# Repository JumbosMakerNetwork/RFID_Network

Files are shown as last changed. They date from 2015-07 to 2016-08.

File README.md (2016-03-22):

# Jumbo's Maker Network - RFID Usage Tracking
This project is an RFID tag and arduino based system for tracking use in a makerspace while also integrating automated safety interlocks through use of data and power relays. 

This includes the firmware and hardware files for the system as well as a series of analytical software used to derive insightful data from the makerspace.

This project is currently in development, so if you stumble across this, please let us know if something doesn't work and feel free to comment to help out if you have some useful feedback.

## Hardware
Contains:
	-Eagle Files, used as design for fabricating circuit boards. There are a variety of circuit boards used in this project, the principal ones being a data interlock board used to interrupt serial communication between devices, and a Pro Shield board, which is used to connect all the components of the RFID reader (e.g. the Mifare Scanner, the LCD monitor..) to the Arduino ESP8266
	-Enclosure files, which are CAD schematics for 3d printing/laser cutting the enclosure that holds all the components

## Scripts
Contains:
	-Several scripts used to initialize new stations and users. These funcitons will eventually be encapsulated by a unified Python data model which will be used for all SQL functions.

## Source Code
Contains:
	-Arduino: the necessary libraries and source code needed for the Arduino microcontrollers powering this system. Within this repo are folders for Signin and Relay stations; Signin stations only have the funcitnality of signin/signout, whereas the relay terminals are capable of restricting power or serial communication between devices.
	-All the php and PSQL initialization tools used to create our PSQL database (in scripts and www)

## Web Analytics
Contains:
	-a set of documents that generate an HTML page featuring visualized data of makerspace usage and new membership over time. This data is collected with python scripts using the pyscopg module, and then interpreted with javascript files utilizing ajax and jquery, finally being visualized with the charts.js library.

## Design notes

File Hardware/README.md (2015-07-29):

# CEEO Makerspace Data Collection - Hardware

## Description
This will be for all the drawings for RFID fobs, terminal enclosures, and PCBs that support the system. 

## To Dos
- ~~ Design Enclosures ~~
- ~~ Finish PCBs ~~
- ~~ Design some RFID key fobs ~~
- ~~ Add Bill of Materials ~~

## Notes

Notes go here

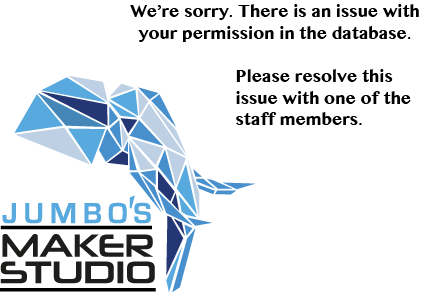
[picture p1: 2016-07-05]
Source_Code/labview/Images/No_ID.png

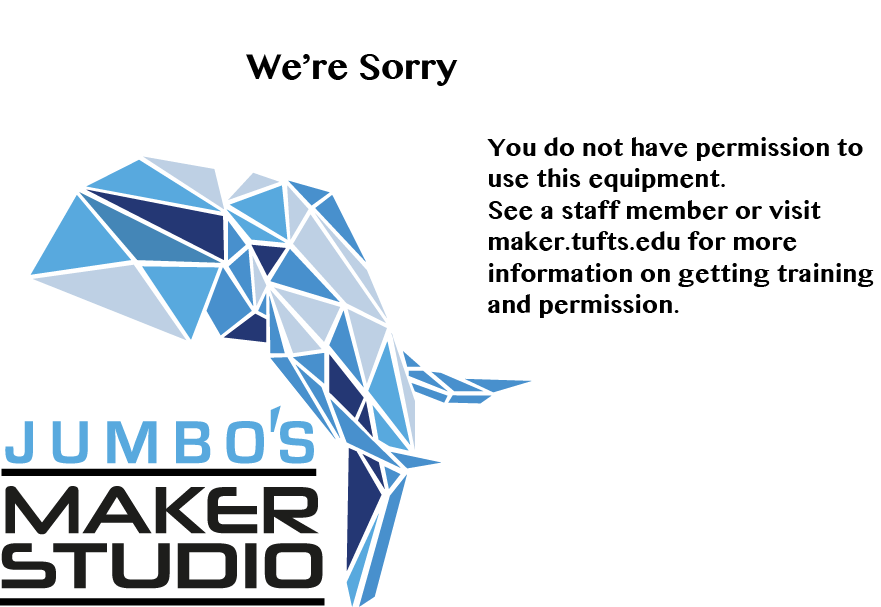
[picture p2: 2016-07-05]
Source_Code/labview/Images/Denied.png

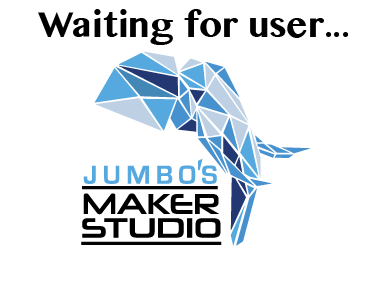
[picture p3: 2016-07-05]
Source_Code/labview/Images/Waiting.png

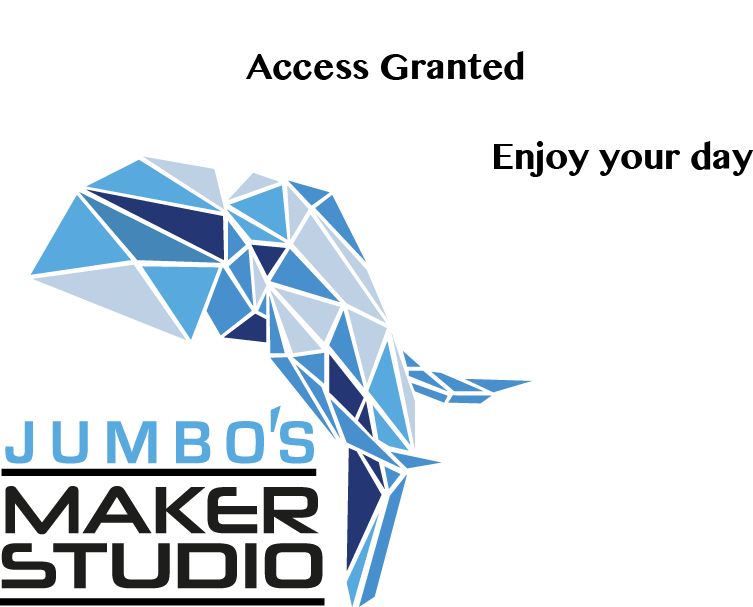
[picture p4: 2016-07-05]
Source_Code/labview/Images/Approve.png

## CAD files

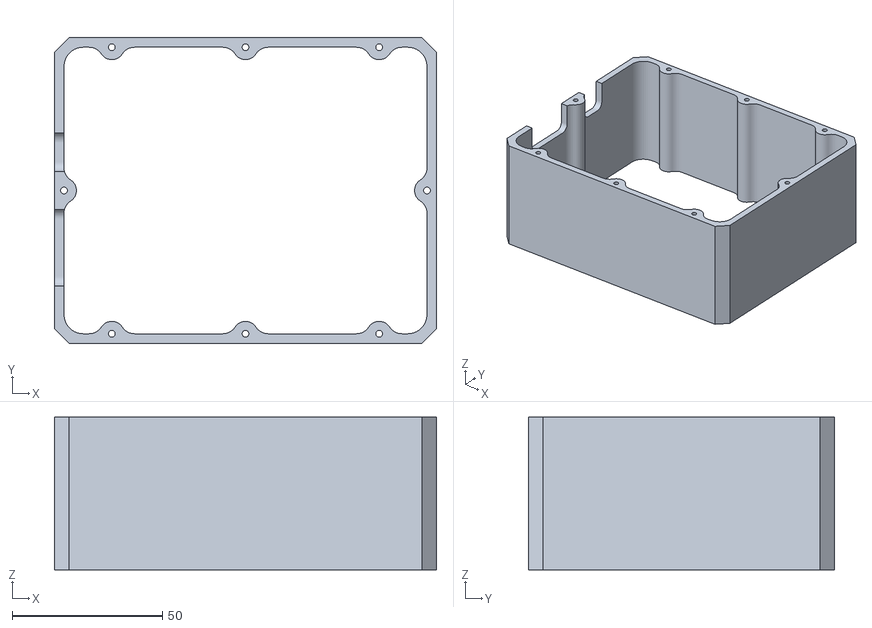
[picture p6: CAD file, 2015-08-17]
Hardware/Enclosure/Signin/Frame.STL
127.0 x 101.6 x 50.8

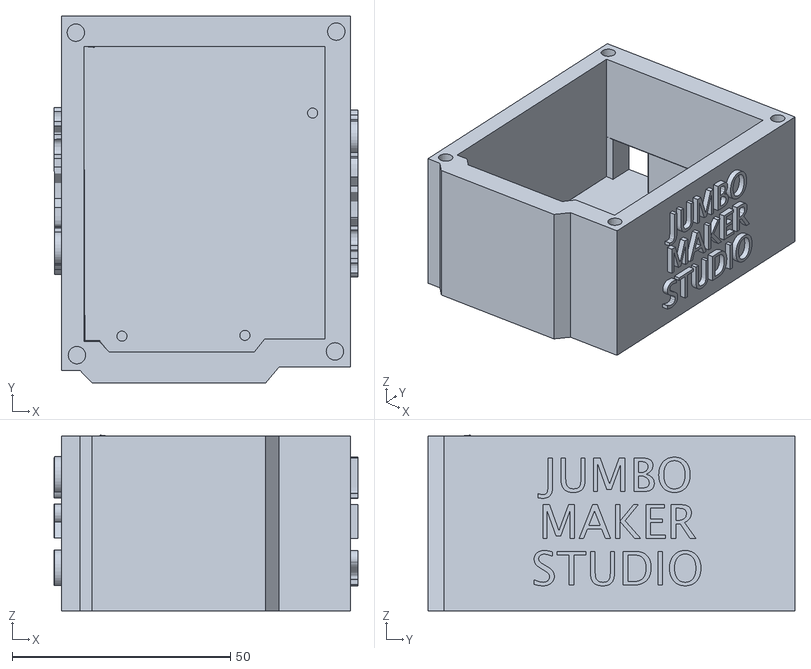
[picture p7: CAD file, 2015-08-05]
Hardware/Enclosure/Signin/V1/Signin Enclosure Bottom.stl
69.5 x 84.0 x 40.3

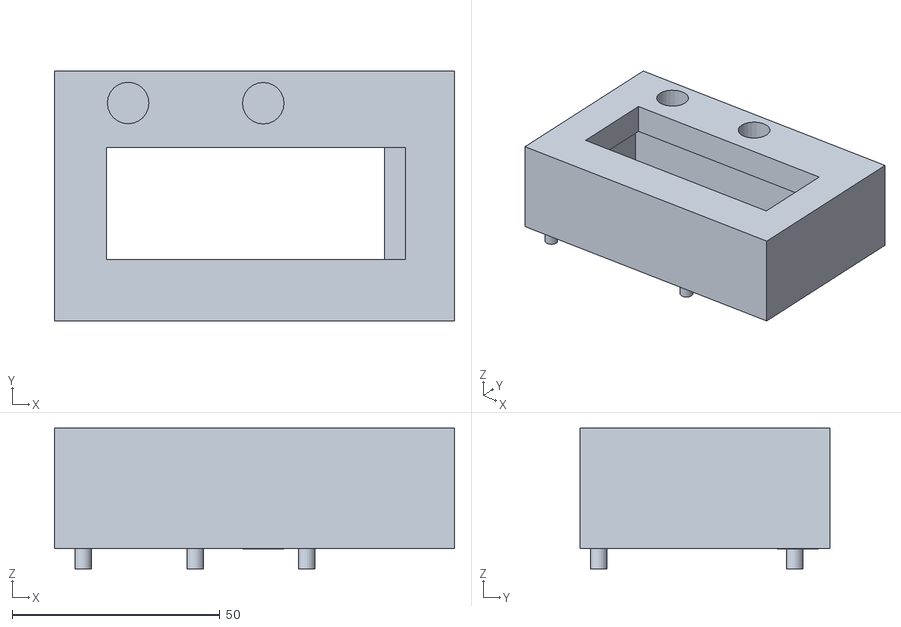
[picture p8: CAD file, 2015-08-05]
Hardware/Enclosure/Signin/V1/Signin Enclosure Top.stl
96.3 x 60.3 x 33.8

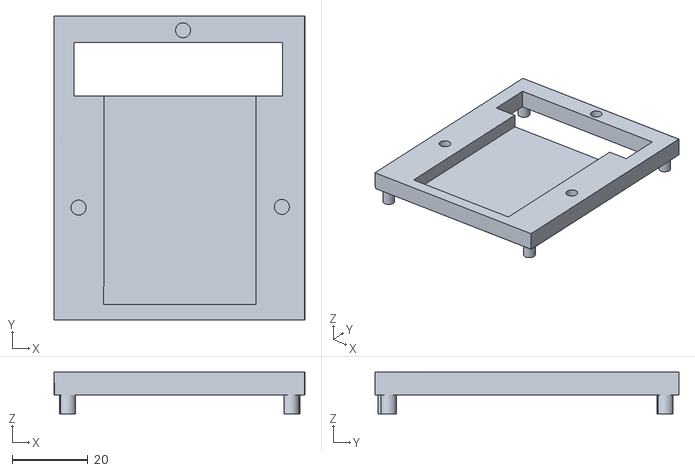
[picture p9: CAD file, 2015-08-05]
Hardware/Enclosure/Signin/V1/Signin Enclosure Middle.stl
66.4 x 80.4 x 11.0

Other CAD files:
Hardware/Enclosure/Signin/V1/SIgnInV1_Assy.skp
Hardware/Enclosure/Signin/V1/Signin Enclosure Bottom.skp
Hardware/Enclosure/Signin/V1/Signin Enclosure Bottom~.skp
Hardware/Enclosure/Signin/V1/Signin Enclosure Middle.skp
Hardware/Enclosure/Signin/V1/Signin Enclosure Top.skp

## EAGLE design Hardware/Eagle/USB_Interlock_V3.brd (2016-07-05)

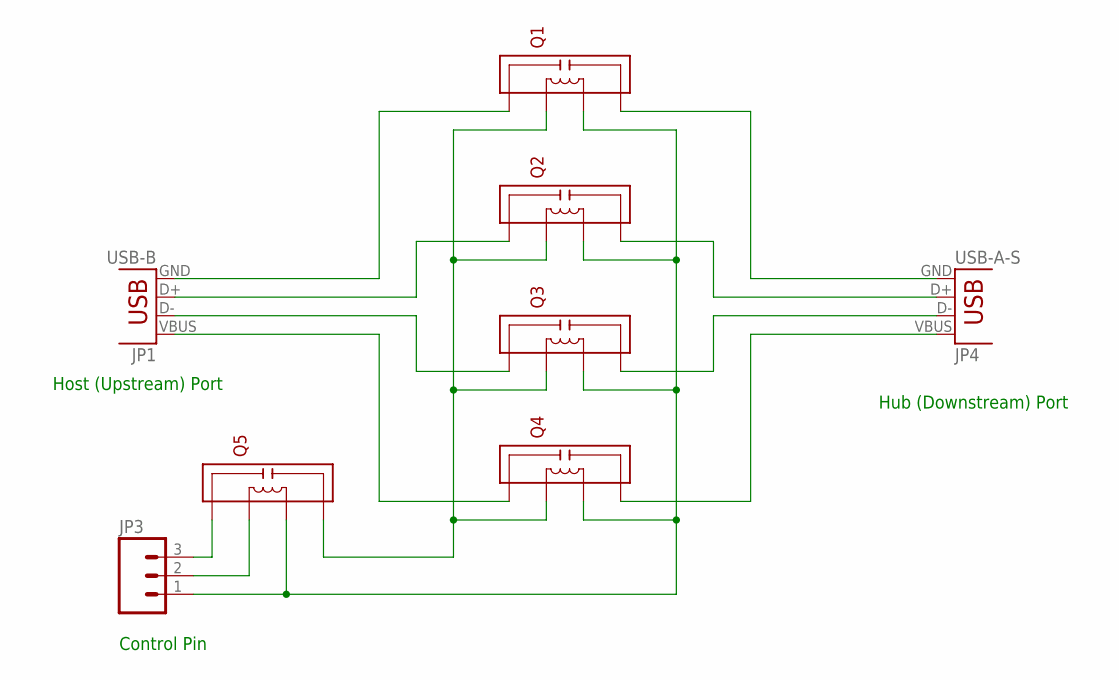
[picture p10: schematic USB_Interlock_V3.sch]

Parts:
JP1: USB-B; USB-B-PTH
JP3: M03LONGPADS; 1X03_LONGPADS
JP4: USB-A-S
Q1, Q2, Q3, Q4, Q5: 9007-12-01

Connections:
GND: JP3.1, Q1.P$3, Q2.P$3, Q3.P$3, Q4.P$3, Q5.P$3
HV1: JP4.D-, Q3.P$4
HV2: JP4.D+, Q2.P$4
LV1: JP1.D-, Q3.P$1
LV2: JP1.D+, Q2.P$1
unnamed: JP3.3, Q5.P$1
unnamed: JP3.2, Q5.P$2
unnamed: Q1.P$2, Q2.P$2, Q3.P$2, Q4.P$2, Q5.P$4
unnamed: JP1.GND, Q1.P$1
unnamed: JP4.GND, Q1.P$4
unnamed: JP1.VBUS, Q4.P$1
V1: JP4.VBUS, Q4.P$4

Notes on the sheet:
Hub (Downstream) Port
Host (Upstream) Port
Control Pin

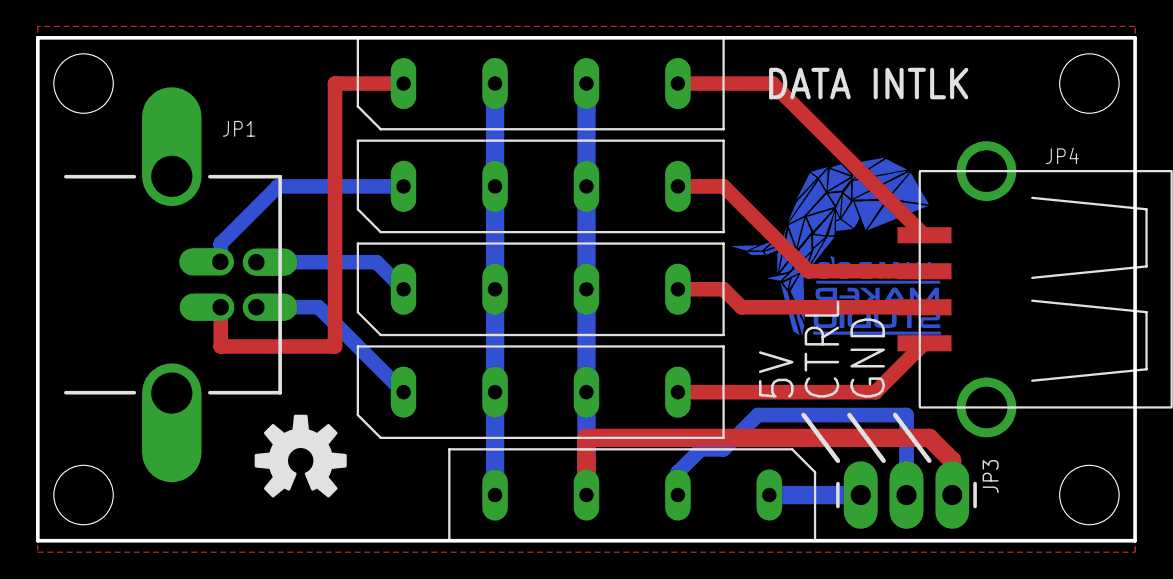
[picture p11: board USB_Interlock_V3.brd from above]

Board: 2 copper layers, 61.0 x 27.9 mm, 14 parts (1 on the bottom side), 12 nets.

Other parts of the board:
U$1: OSHW-LOGO-M
U$2, U$3, U$4, U$5: STAND-OFF
U$7: JMS_LOG_COPPER

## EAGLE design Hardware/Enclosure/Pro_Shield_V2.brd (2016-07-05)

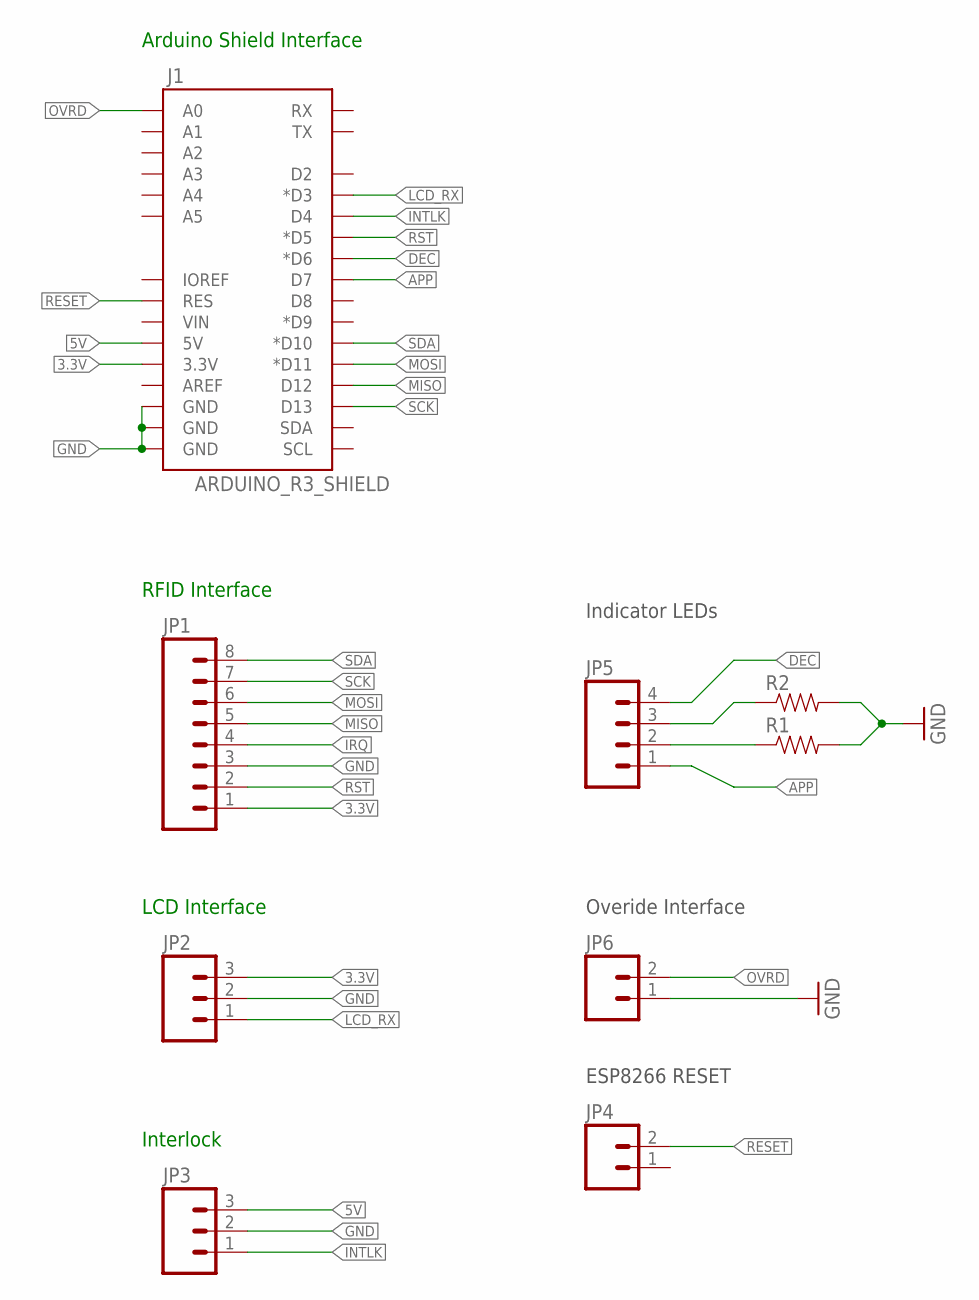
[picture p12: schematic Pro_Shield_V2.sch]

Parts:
J1: ARDUINO_R3_SHIELD; UNO_R3_SHIELD
JP1: M08LONGPADS; 1X08_LONGPADS
JP2, JP3: M03LONGPADS; 1X03_LONGPADS
JP4, JP6: M02LOCK_LONGPADS; 1X02_LOCK_LONGPADS
JP5: M04LONGPADS; 1X04_LONGPADS
R1, R2: RESISTORPTH-1/4W; AXIAL-0.4

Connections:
3.3V: J1.3.3V, JP1.1, JP2.3
5V: J1.5V, JP3.3
APP: J1.D7, JP5.1
DEC: J1.D6 (*D6), JP5.4
GND: J1.GND@0 (GND), J1.GND@1 (GND), J1.GND@2 (GND), JP1.3, JP2.2, JP3.2, JP6.1, R1.P$2 (2), R2.P$2 (2)
INTLK: J1.D4, JP3.1
IRQ: JP1.4
LCD_RX: J1.D3 (*D3), JP2.1
MISO: J1.D12, JP1.5
MOSI: J1.D11 (*D11), JP1.6
unnamed: JP5.2, R1.P$1 (1)
unnamed: JP5.3, R2.P$1 (1)
OVRD: J1.A0, JP6.2
RESET: J1.RES, JP4.2
RST: J1.D5 (*D5), JP1.2
SCK: J1.D13, JP1.7
SDA: J1.D10 (*D10), JP1.8

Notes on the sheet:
LCD Interface
RFID Interface
Arduino Shield Interface
Indicator LEDs
Overide Interface
Interlock
ESP8266 RESET

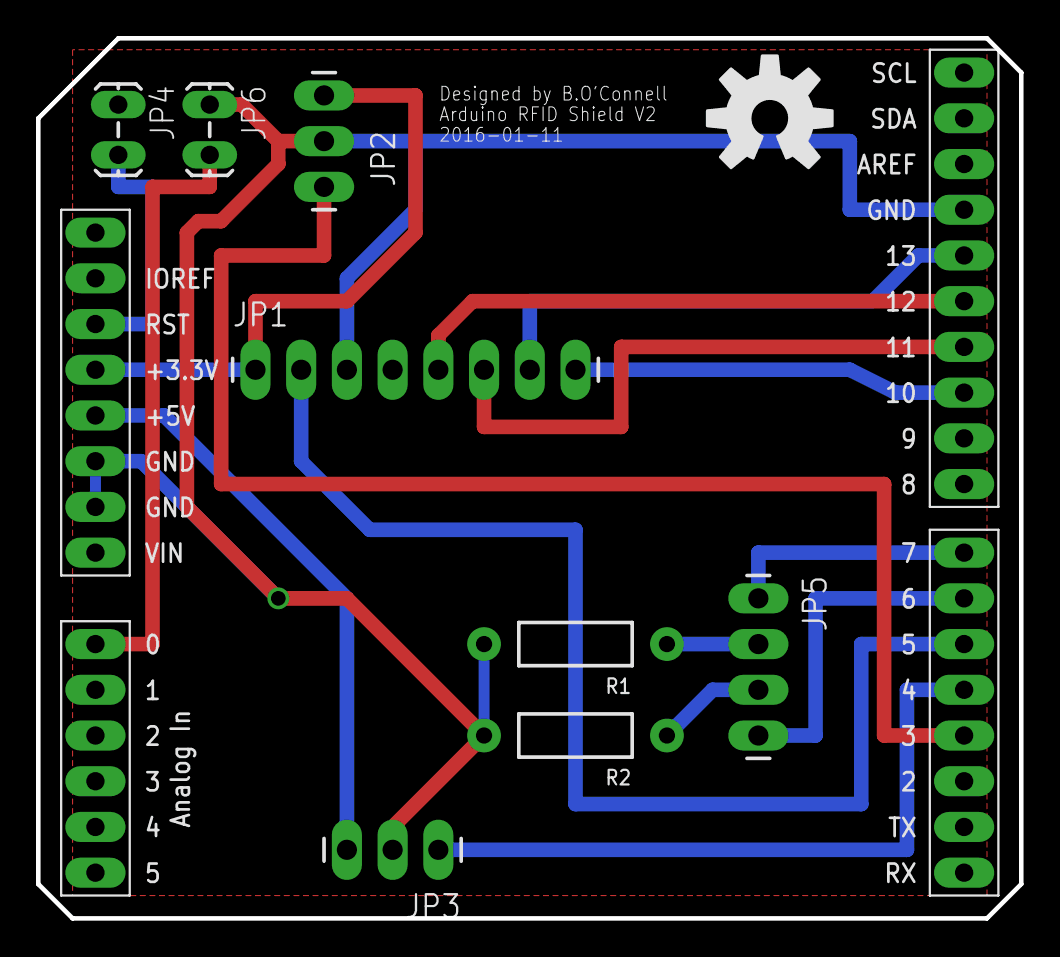
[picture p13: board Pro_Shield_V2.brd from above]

Board: 2 copper layers, 54.6 x 48.9 mm, 10 parts (0 on the bottom side), 16 nets.

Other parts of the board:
U$1: OSHW-LOGO-L

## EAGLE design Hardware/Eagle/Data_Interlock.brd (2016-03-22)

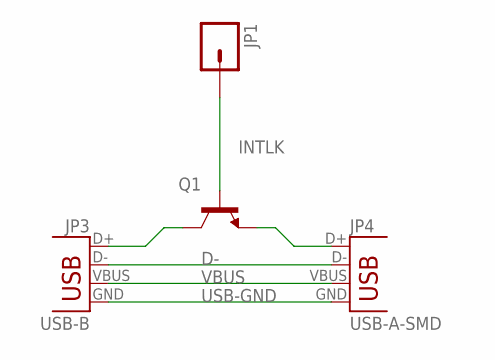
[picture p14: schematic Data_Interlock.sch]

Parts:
JP1: M01PTH_LONGPAD; 1X01_LONGPAD
JP3: USB-B; USB-B-PTH
JP4: USB-A-SMD; USB-A-S-NOSILK-FEMALE
Q1: TRANSISTOR_NPNBC547; TO-92-AMMO

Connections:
D-: JP3.D-, JP4.D-
INTLK: JP1.1, Q1.2 (B)
unnamed: JP3.D+, Q1.1 (C)
unnamed: JP4.D+, Q1.3 (E)
USB-GND: JP3.GND, JP4.GND
VBUS: JP3.VBUS, JP4.VBUS

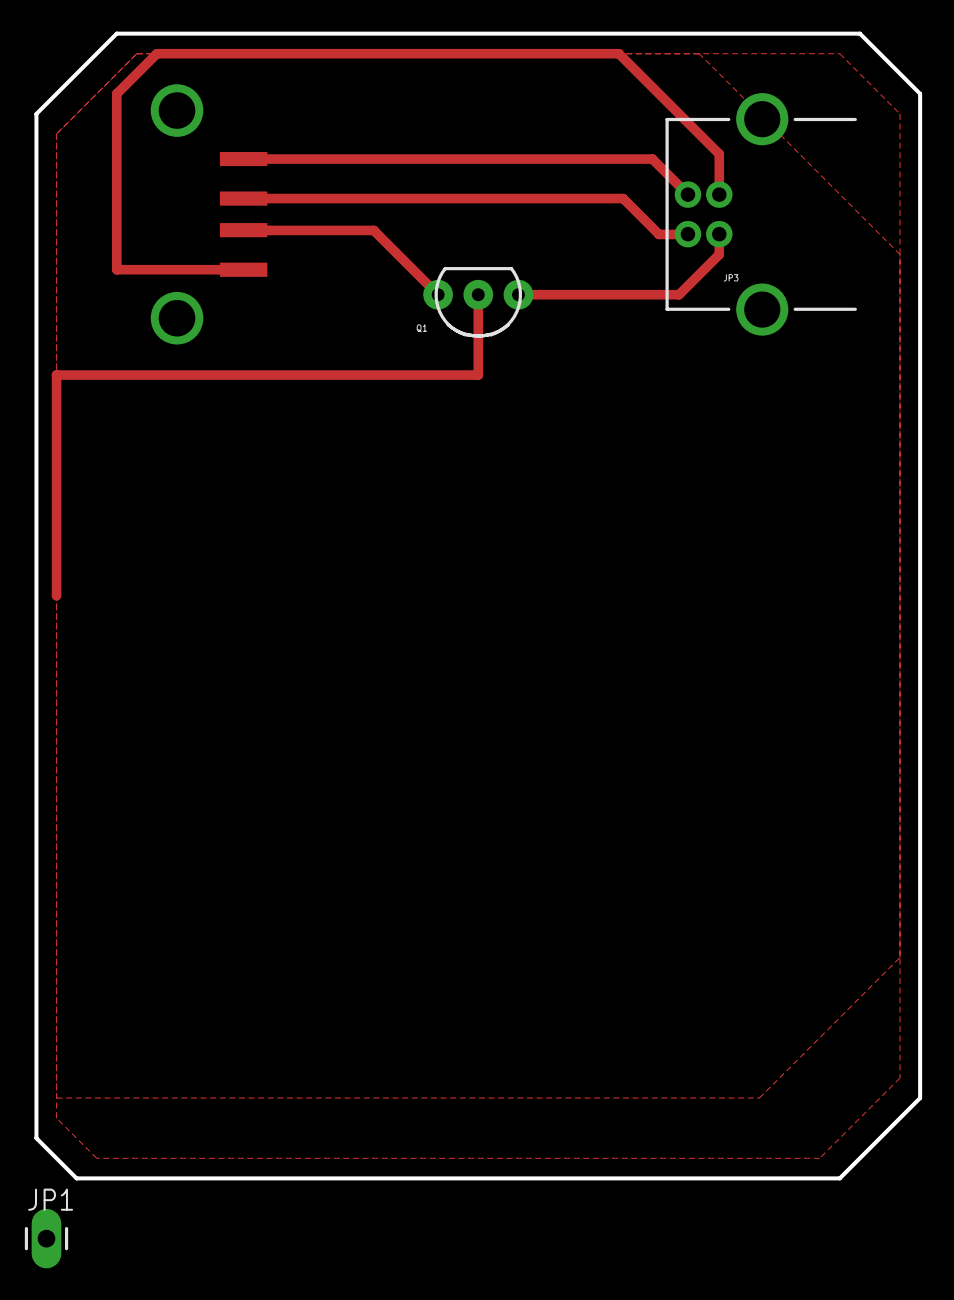
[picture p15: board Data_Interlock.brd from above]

Board: 2 copper layers, 55.9 x 72.4 mm, 4 parts (0 on the bottom side), 6 nets.

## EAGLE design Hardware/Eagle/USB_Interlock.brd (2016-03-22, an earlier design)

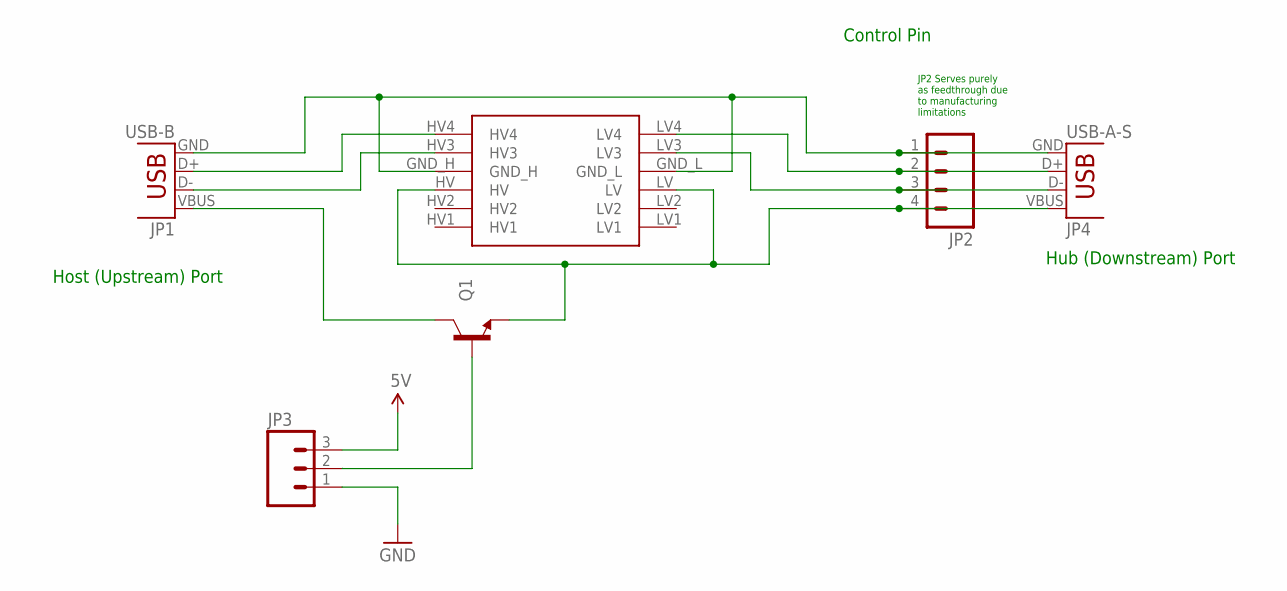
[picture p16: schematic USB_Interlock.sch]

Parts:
JP1: USB-B; USB-B-PTH
JP2: M04LONGPADS; 1X04_LONGPADS
JP3: M03LONGPADS; 1X03_LONGPADS
JP4: USB-A-S
Q1: TRANSISTOR_NPNBC547; TO-92-AMMO
U$1: LOGIC_LEVEL_CONVERTER

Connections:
5V: JP3.3
CTRL: JP3.2, Q1.2 (B)
GND: JP1.GND, JP2.1, JP3.1, JP4.GND, U$1.GND_H, U$1.GND_L
unnamed: JP2.4, JP4.VBUS, Q1.3 (E), U$1.HV, U$1.LV
unnamed: JP2.2, JP4.D+, U$1.LV4
unnamed: JP2.3, JP4.D-, U$1.LV3
unnamed: JP1.D+, U$1.HV4
unnamed: JP1.D-, U$1.HV3
unnamed: JP1.VBUS, Q1.1 (C)

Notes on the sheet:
Hub (Downstream) Port
Host (Upstream) Port
Control Pin
JP2 Serves purely as feedthrough due to manufacturing limitations

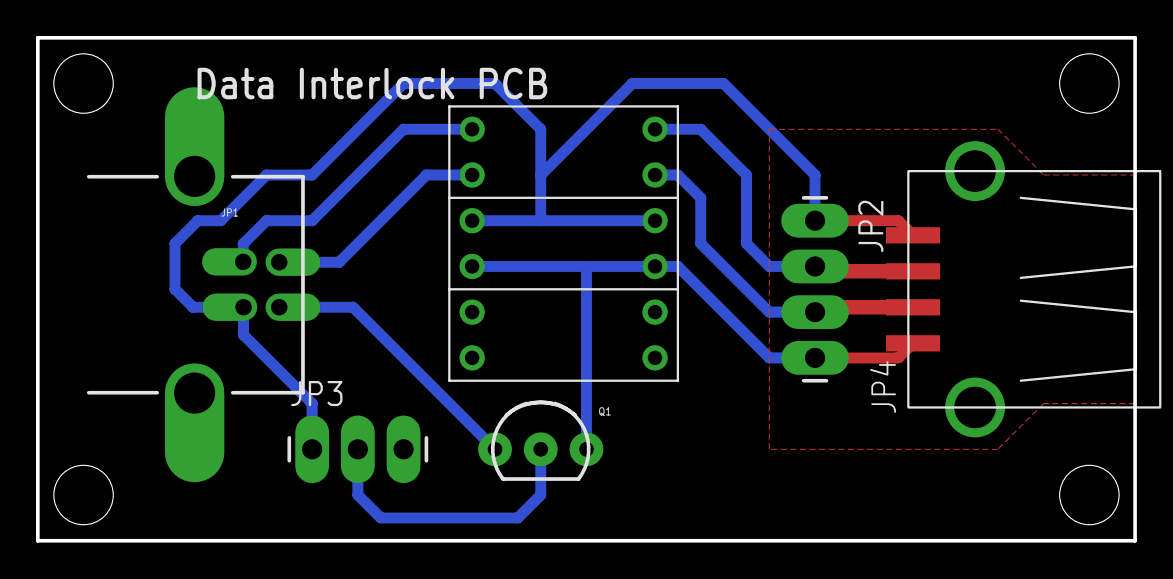
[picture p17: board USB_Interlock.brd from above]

Board: 2 copper layers, 61.0 x 27.9 mm, 10 parts (0 on the bottom side), 8 nets.

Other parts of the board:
U$2, U$3, U$4, U$5: STAND-OFF

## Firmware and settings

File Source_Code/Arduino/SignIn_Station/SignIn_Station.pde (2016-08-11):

#include <SPI.h>
#include <MFRC522.h>
#include <SoftwareSerial.h>

// WARNING, WARNING ... DANGER, WILL ROBINSON, DANGER!!!
// The station ID is unique to each terminal and must be manually entered.
// Double and triple check this value is what you intend it to be.
//#define SID 2  // Station ID number  - needs to correlate with database setting

//////////////////////// Wireless network information //////////////////////////////////

const char SSID[] = "Tufts_Wireless";

// PW = Empty string since network is not password protected. This particular network is 
// mac address registry based. We are not registering the mac addresses of these so
// they are limited to accessing internal IPs or websites hosted by Tufts. 
const char PSK[] = ""; 
// Static IP of the directory location
const char DBIP[] = "130.64.17.0";

#define STID 16                  // Station ID number 
#define RST_PIN   5   
#define SS_PIN    10 

///////////////////////////////// RFID Inits /////////////////////////////////////////

// RFID_UID will be stored and sent as a hex string
String RFID_UID ="";
MFRC522 RFID(SS_PIN, RST_PIN);  // Create mfrc522 instance
MFRC522::MIFARE_Key key;

/////////////////////////////////// Hardware assignments /////////////////////////////

SoftwareSerial ESP8266(8, 9); // D9 -> ESP8266 RX, D10 -> ESP8266 TX
SoftwareSerial LCD(3,2);        // D2 -> LCD TX, D3 -> LCD RX (unused)
#define greenLED 7
#define redLED   6
#define esp8266_rst_pin  A1
#define rst_pin_value 170
#define reset_delay 1000



void setup() {
    pinMode(esp8266_rst_pin, OUTPUT);
    digitalWrite(esp8266_rst_pin, LOW);
    pinMode(redLED, OUTPUT);
    pinMode(greenLED, OUTPUT);

    // Initialize Serial Communications
    Serial.begin(9600);   // with the PC for debugging displays
    DisplayInit();        // Start and Configure LCD for external displays
    ESP8266.begin(9600);
    display("Welcome", "");

    while(!ESP8266_Check()){ delay(reset_delay); }
    display("esp8266", "checked!");
    Serial.println(F("esp8266 checked!"));

    while( !ESP8266_Mode(3) ){ delay(reset_delay); }
    Serial.println(F("esp8266 set to mode 3!"));

    display("Connecting", "To Wifi...");
    while( !connectWiFi() ){ delay(reset_delay); }
    Serial.println(F("esp8266 successfully connected to wifi!"));

    display("Waiting for", "RFID..");
    delay(500);

    SPI.begin();      
    RFID.PCD_Init();     

    // Prepare the key (used both as key A and as key B)
    // using FFFFFFFFFFFFh which is the default at chip delivery from the factory
    for (byte i = 0; i < 6; i++) {
       key.keyByte[i] = 0xFF;
    }
    GetRFID(key.keyByte, MFRC522::MF_KEY_SIZE);
}


void loop() {
    delay(1000);
    do {
        //for debugging: wait for serial commands while looping
        while(ESP8266.available()) Serial.write(ESP8266.read());
        while(Serial.available()) ESP8266.write(Serial.read());

        check_status();
        delay(100);
    } while ( !getPICC() );

    Serial.println(F("An RFID has been detected"));
    RFID_UID = GetRFID(RFID.uid.uidByte, RFID.uid.size);

    display("RFID", "Detected!");
    String info = "SignIn"; // Info constant for Sign IN/OUT stations.

    RFID.PICC_HaltA();       // Halt PICC
    RFID.PCD_StopCrypto1();  // Stop encryption on PCD

    String resp = "";
    resp = ReqJMN( RFID_UID, "3", info);
    Serial.println(resp);

    if (resp[0] == 'T') {
        digitalWrite(greenLED, HIGH);
        String name = getName(resp);
        Serial.println(resp);
        Serial.println(name);

        display("Thank you, ", name);
        delay(3000);
        digitalWrite(greenLED, LOW);  
    }

    else if (resp[0] == 'F') {
        digitalWrite(redLED, HIGH);  
        display("Insufficient","credentials");
        delay(2000);
        display("Get approved at","maker.tufts.edu");
        delay(2000);
        digitalWrite(redLED, LOW);  
    }

    else if (resp[0] == 'E') {
        // Blink the red light and give an error message.
        // Display a warning to get a staff member. 
        display("No ID found","in Database");
        digitalWrite(redLED, HIGH);  
        delay(3000);
        display("Get approved at","maker.tufts.edu"); 
        digitalWrite(redLED, LOW);
        delay(3000);
    }

    display("Waiting for", "RFID..");
}



//////////////////////RFID UTILITY FUNCTIONS//////////////////////
//////////////////////////////////////////////////////////////////

// Grab the hex values from a byte array, returns decimal equivalent
int getPICC() 
{
  // Getting ready for Reading PICCs
  if ( ! RFID.PICC_IsNewCardPresent()) { //If a new PICC placed to RFID reader continue
    return 0;
  }
  if ( ! RFID.PICC_ReadCardSerial()) {   //Since a PICC is placed, get Serial and continue
    return 0;
  }

  return 1;
}

String GetRFID(byte *buffer, byte bufferSize) 
{
  Serial.println(F("Get RFID called."));
  String tmp = "";
  String tmp2;
  for (byte i = 0; i < bufferSize; i++) {
    tmp2 = "";
    tmp2 += String(buffer[i] < 0x10 ? "0" : "");
    tmp2 += String(buffer[i], HEX);
    tmp = tmp2 + tmp;
  }
  tmp.toUpperCase();
  return tmp;
}


////////////////////////////////////////////////////////////////////////
/////////////////////// WIFI / DATABASE UTILITIES //////////////////////
////////////////////////////////////////////////////////////////////////
boolean ESP8266_Check()
{ 
    ESP8266.println(F("AT"));
    delay(200);
    if(ESP8266.find("OK")) {
      Serial.flush();
      return true;
    }
    
    else if(ESP8266.find("ERROR")) {
      Serial.println(F("RECEIVED: Error"));
      Serial.println(F("Trying again.."));
      return false;
    }
    else {
      Serial.println(F("RECEIVED: No Response"));
      Serial.println(F("Trying again.."));
      return false;
    }
}

boolean ESP8266_Mode(int mode)
{
    ESP8266.println(F("AT+CWMODE?"));
    if(ESP8266.find(mode)) {
      Serial.print(F("Mode already set"));
      return true;
    }

    ESP8266.print(F("AT+CWMODE="));
    ESP8266.println(mode);
    
    if(ESP8266.find("OK")) {
      Serial.println(F("RECEIVED: OK"));
      return true;
    }
    else if(ESP8266.find("ERROR")) {
      Serial.println(F("RECEIVED: Error"));
      Serial.println(F("Trying again.."));
      return false;
    }
    else {
      Serial.println(F("RECEIVED: No Response"));
      Serial.println(F("Trying again.."));
      //reset device
      void(* resetFunc) (void) = 0;
      resetFunc();
      return false;
    }
    delay(100);
}


boolean connectWiFi()
{
    ESP8266.println(F("AT+CWJAP?"));
    delay(250);
    if(ESP8266.find("tuftswireless")) 
    {
        Serial.flush();
        while(ESP8266.available()) Serial.write(ESP8266.read());
        Serial.print(F("\n"));  
        // Serial.println(F("Already connected"));
        return true;
    }
    delay(100);
    String cmd="AT+CWJAP=\"";
    cmd+=SSID;
    cmd+="\",\"";
    cmd+=PSK;
    cmd+="\"";
    ESP8266.println(cmd);
    Serial.println(cmd);
    delay(500);
    while ( !ESP8266.available() ){
        delay(100);
    }

    if(ESP8266.find("OK")) {
        Serial.println(F("RECEIVED: OK"));
        ESP8266.flush();
        return true;
    }

    else if(ESP8266.find("ERROR")) {
        Serial.println(F("RECEIVED: Error"));
        return false;
    }

    else {
        Serial.println(F("RECEIVED: Couldn't connect to wifi; no response"));
        return false;
    }
}


String ReqJMN(String RFID1, String req1, String info1)
{
    String resp="";
    char z;
    Serial.println(F("Starting request..."));


    String httpReq = "GET /RFID.php?stid=";
    httpReq += STID; // Universal constant
    httpReq += "&rfid=";
    httpReq += RFID1; // Local input
    httpReq += "&req=";
    httpReq += req1; // local input
    httpReq += "&info=";
    httpReq += info1; // local input
    httpReq += " HTTP/1.0\r\n\r\n";
    delay(50);
    Serial.println(httpReq);
    //  Send AT command to ESP8266
    // Start connection - 
    Serial.println(F("CIPStart..."));
    Serial.print(F("AT+CIPSTART=\"TCP\",\""));
    Serial.print(DBIP);
    Serial.print(F("\",80\r\n"));

    ESP8266.print(F("AT+CIPSTART=\"TCP\",\""));
    ESP8266.print(DBIP);
    ESP8266.print(F("\",80\r\n"));

    delay(100);
    if(ESP8266.find("OK")) {
      Serial.println(F("CIPSTART: OK"));
    }
    
    else if(ESP8266.find("ERROR")) {
      Serial.println(F("CIPSTART: Error"));
      return "Error";
    }

    else {
      Serial.println(F("CIPSTART: No Response"));
      return "Error";
    }

    // Send request - 
    Serial.println(F("CIPSEND..."));
    Serial.print(F("AT+CIPSEND=")); 
    Serial.print(httpReq.length());
    Serial.print(F("\r\n"));

    ESP8266.print("AT+CIPSEND="); 
    ESP8266.print(httpReq.length()); // Specifies how much data is being sent
    ESP8266.print("\r\n");
    // while(ESP8266.available()) Serial.write(ESP8266.read());
    delay(500);

    if(ESP8266.find("OK")) {
      Serial.println(F("Sent Request - "));
      Serial.print(httpReq);
      ESP8266.print(httpReq);
    }
    else {
      Serial.println(F("No request sent. Try again."));
    }

    int j = 0;
    while(!ESP8266.find("JMNR:")) {
      j++;
      Serial.print(j);
      if (j>50) {
        Serial.println(F("Error - could not find JMNR"));
        return F("Error - could not find JMNR");
      }
    }

    Serial.println(F("Found JMNR:..."));
    for (int i = 0; i<=18; i++) {
      while(!ESP8266.available());
      z = (char)ESP8266.read();
      Serial.write(z);
      resp.concat(z);
    }

    Serial.println(F("<-- END"));

    return resp;
}



////////////////////////////////////////////////////////////////////////
////////////////// MISC UTILITIES ///////////////////////////////////
//////////////////////////////////////////////////////
void check_status()
{
      if( !ESP8266_Check() ) {
              display("Terminal", "Disconnected");
              while(!ESP8266_Check()) {
                    delay(reset_delay);
              }
              display("Terminal", "Connected");
              Serial.println("Terminal Connected.");
              delay(200);
              display("Waiting for", "RFID..");
       }
       /* if( !connectWiFi() ) {
              display("Wifi", "Disconnected");
              while(!connectWiFi()) {
                    delay(reset_delay);
              }
              display("Wifi", "Connected");
              delay(200);
              display("Waiting for", "RFID..");
       } */
}
// Function for sending strings to the display
void display(String Line1, String Line2)
{
  // Clear the display
  LCD.write(254); LCD.write(128);
  LCD.write("                "); // clear display (16 characters each line)
  LCD.write("                ");

  Line1 = center(Line1);
  Line2 = center(Line2);

    // Concatenate the strings
  char L1[ ] = "                "; // 16 Characters
  char L2[ ] = "                "; // 16 Characters
  Line1.toCharArray(L1, 16);
  Line2.toCharArray(L2, 16);
  
  LCD.write(254); LCD.write(128); // First line
  LCD.write(L1);

  LCD.write(254); LCD.write(192); // Second line
  LCD.write(L2);

  delay(25);
}

String getName(String response)
{
    Serial.println(F("In getname"));
    response.remove(0,2);   //removes 'T' and a whitespace, also, this fxn is
                            //pass by copy, so we're not altering the reponse from before
    Serial.println(response);

    //find whitespace after name
    int k = 0;
    for(k; k < response.length(); k++) {
        if(response[k] == ' '){
          break;
        }
    }

    int j = (16 - k);
    // now remove everything after index k, up to the last index (index 15)
    response.remove(k, j);

    return response;
}

void DisplayInit()
{
  LCD.begin(9600);
  delay(100);
  // To be run during splash screen to ensure running at 9600
  LCD.write(0X7C); LCD.write(0X12);
  delay(500);
  // Reset the brightness to 40%
  LCD.write(0X7C); LCD.write(140);
  delay(100);
  // Clear Screen
  LCD.write(0X7C); LCD.write(0X01);
  delay(100);
}

String center(String toCenter)
{
    // Auto center the strings
    int a = toCenter.length();
    a = a + (a % 2);  //makes divisible by 2
    a = 16 - a;
    a = a/2;
    String center1 = "";
    
    //for loop concatenates whitespaces to beginning of new array
    for (a; a > 0; a--){    
        center1 += ' ';
    }
    center1 += toCenter;
    return center1;
}

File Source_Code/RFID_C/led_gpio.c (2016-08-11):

/*
 * HW_GPIO.c
 *	
 *  by Will Dolan, June 2016
 */

#include <errno.h>
#include <stdlib.h>
#include <stdio.h>
#include <string.h>
#include <wiringPi.h>
#include <wiringSerial.h>
#include <time.h>
 #include <unistd.h>
#include "led_gpio.h"

 #define greenLED 29
 #define redLED	  28
 #define relayPin 27
 #define LCD_3v3  1
 #define HELP_BUTTON 24
 #define PHOTO_BUTTON 25

int LCD;
char *LCD_buff1;
char *LCD_buff2;

// Returns the device address of the LCD monitor, or -1 if failure
void init_GPIO()
 {
        wiringPiSetup();
	pinMode(greenLED, OUTPUT);     
	pinMode(redLED, OUTPUT);    
        pinMode(relayPin, OUTPUT); 
        pinMode(HELP_BUTTON, INPUT);
        pinMode(LCD_3v3, OUTPUT);
        digitalWrite(LCD_3v3, LOW);  
        printf("Pi initialized, ready for RFID.\n");
 }

 void activate_LCD()
 {
        LCD_buff1 = (char *)calloc(16, 1);
        LCD_buff2 = (char *)calloc(16, 1);
        digitalWrite(LCD_3v3, HIGH); 
        delay(100);
        if ((LCD = serialOpen ("/dev/ttyAMA0", 9600)) < 0) {
                fprintf (stderr, "Unable to open serial device: %s\n", strerror (errno)) ;
                return;
        }
	char clearcmd[2] = { 254, 1 };
        write(LCD, clearcmd, 2);

        display("Welcome,", "Terminal ready.");
        delay(1000);
        display("Waiting for", "RFID...");
 }

 void displayIP(char input[])
 {
        printf("Read from stdin:\n%s\n",input);
        char line1[16];
        char line2[16];
        int i = 0;
        int j = 0;
        int whitespace = 0;

        while((input[i] != '\0') && (input[i] != '\n') && (i<15)) {
            if (input[i] == ' '){
                whitespace = 1;
                break;
            }
            line1[i] = input[i];
            i++;
        }
        line1[i] = '\0';
        
        if(whitespace == 1){
            printf("Found whitespace.\n");
            i++;
            while((input[i] != '\0') && (input[i] != '\n') && (j < 15)){
                line2[j] = input[i];
                i++; j++;
            }
        }
        line2[j] = '\0';

        printf("Line 1:\n%s\n",line1);
        printf("Line 2:\n%s\n",line2);

        display("Current IP", "Address:");
        delay(1500);
        display(line1, line2);
        delay(5000);
        display("Waiting for", "RFID...");
 }

 int readHelp(int initHelpState)
 {
        return (digitalRead(HELP_BUTTON) != initHelpState);
 } 
 
 int readPhoto(int initPhotoState)
 {
        return (digitalRead(PHOTO_BUTTON) != initPhotoState);
 }

 time_t beginUse(char *resp) 
{
        char *name = (char *)calloc(16,1);
        digitalWrite(greenLED, HIGH);
        digitalWrite(relayPin, HIGH);
        getName(name, resp);
        display("Welcome", name);
        free(name);
        delay(2000);
        digitalWrite(greenLED, HIGH);
        digitalWrite(relayPin, HIGH);
        display("Commence","Use...");
        time_t curr_time;
        curr_time = time(NULL);
        return curr_time;
}
void rejectUse()
{
        digitalWrite(redLED, HIGH);  
        display("Insufficient","credentials");
        delay(1000);
        display("Get approved at","maker.tufts.edu");
        delay(1000);
        digitalWrite(redLED, LOW);
        digitalWrite(relayPin, LOW);
        display("Waiting for", "RFID..");
}
void noUserHandler()
{
        display("No ID found","in Database");
        digitalWrite(relayPin, LOW);
        digitalWrite(redLED, HIGH);  
        delay(1000);
        display("Get approved at","maker.tufts.edu"); 
        digitalWrite(redLED, LOW);
        delay(1000);
        display("Waiting for", "RFID..");
}

int endUse(time_t start_time)
{
        display("Goodbye!", "Signed out!");
        time_t curr_time;
        curr_time = time(NULL);        
        int time_diff = (int)difftime(curr_time, start_time);

        digitalWrite(greenLED, LOW);
        digitalWrite(relayPin, LOW);
        delay(1000);
        display("Waiting for", "RFID..");
        return time_diff;
}

void contact_admin()
{
        display("Administrator","Contacted.");
        delay(2500);
        display("Please wait,","help is coming!");
        delay(2500);  
        display("Waiting for", "RFID..");
}
void sendHelp()
{
        display("Help","Requested!");
        delay(1500);                
        display("Check email","for info");
        delay(2000);                
        display("or press again","to call admin.");
        delay(1500);        
        display("Commence","Use...");
}

void display(char *line1, char *line2)
{
        char line1cmd[2] = { 254, 128 };
        char line2cmd[2] = { 254, 192 };

        center(LCD_buff1, line1);
        center(LCD_buff2, line2);

        write(LCD, line1cmd, 2);
        serialPuts(LCD, LCD_buff1);
        write(LCD, line2cmd, 2);
        serialPuts(LCD, LCD_buff2);
}
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

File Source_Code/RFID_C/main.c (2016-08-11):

/*
 * main.c
 *	
 *  by Will Dolan, June 2016
 */

#include <stdlib.h>
#include <stdio.h>
#include <time.h>
#include "rfid.h"
#include "curl_req.h"
#include "led_gpio.h"
#include "camera.h"
#include <errno.h>
#include <string.h>
#include <wiringPi.h>
#include <wiringSerial.h>
 #include <unistd.h>

#define x_ms 500L
void sleep_for_x_ms();
void readIP();
void get_sid();

char RFID_UID[10];
char stid[10];
/* Main :
 *      First, initialize RFID and GPIO components
 *      If the -IP flag is raised, display the IP address, read from stdin
 *      Then, enter loop. Wait for RFID, then 
 *      send a //request to JMN DB w/ RFID, then take appropriate action
 *      based on response. Look for help/photo button depress throughout loop.
*/
int main(int argc, char *argv[])
{       
	get_sid();
    char *RFID_UID = (char *)calloc(10,1);
    char *JMN_resp = (char *)calloc(512,1);

	init_RFID();
	init_GPIO();
	delay(9000);
	activate_LCD();

	if(argc > 1) {
		if(strcmp(argv[1], "-IP") == 0) {
		        readIP();
		}
    }

	int status = 0;
	int use_time = 0;
	int admin_help = 0;
	char use_time_s[16];
	int initHelpState = readHelp(0);
	int initPhotoState = readPhoto(0);
	
	while(1) {
		sleep_for_x_ms();		
		status = look_for_RFID();

                if(status == 1){
                        get_RFID(RFID_UID);
                        printf("New tag: %s\n", RFID_UID);
			if(strcmp(RFID_UID, "") == 0) {
				display("RFID read error","Try again.");
			}
			else {
				ReqJMN(JMN_resp, RFID_UID, "1", "begin", stid);

				if (strchr(JMN_resp,'T') != NULL) {
					time_t begin_t = beginUse(JMN_resp);
					while(status == 1){
						sleep_for_x_ms();		
						if(readHelp(initHelpState) == 1){
							if(admin_help == 0) {
								sendHelp(RFID_UID);
								ReqJMN(JMN_resp, RFID_UID, "4", "help_email", stid);
								admin_help = 1;
							} else {
								contact_admin();
								ReqJMN(JMN_resp, "0", "4", "contact_admin", stid);
							}
						}
						if(readPhoto(initPhotoState) == 1){
							display("Photo Snapped!","Uploading...");
							char *time_file = (char *)calloc(25,1);
							takePicture(time_file, RFID_UID);
							//ReqJMN(JMN_resp, RFID_UID, "5", time_file, stid);
							free(time_file);
							display("Image uploaded!","See email.");
							delay(2000);
							display("Commence","Use...");
						}
						status = look_for_RFID();
						status = look_for_RFID();
						//need to call twice! don't touch.****
					}
					use_time = endUse(begin_t);
					sprintf(use_time_s, "%d", use_time);
					ReqJMN(JMN_resp, RFID_UID, "2", use_time_s, stid);
					admin_help = 0;
				}

				else if (strchr(JMN_resp,'E') != NULL) {
					rejectUse();
				} 
				else noUserHandler();

				RFID_refresh();
			}
                }
                
                if(readHelp(initHelpState) == 1) {
                        contact_admin();
                        ReqJMN(JMN_resp, "0", "4", "contact_admin", stid);
                }
	}
        RFID_end();
        GPIO_end();
        free(RFID_UID);
        free(JMN_resp);
        return 0;
}
void get_sid()
{
	FILE *fp = fopen("sid.txt", "r");
	if(fp == NULL) {
		printf("Error opening station identifier\n");
	}
	else if(fgets(stid, 10, fp) != NULL) {
		printf("Successfully assigned station %s \n", stid);
		fclose(fp);
	}
}

void sleep_for_x_ms()
{
	struct timespec tim, tim2;
	tim.tv_sec  = 0;
	tim.tv_nsec = (x_ms * 1000000L); 
	nanosleep(&tim , &tim2);
}

void readIP()
{
        char input[64];
        fgets(input,64,stdin);
        displayIP(input);
}
//char *//ReqJMN(char *RFID, char *//req, char *info, char* station);

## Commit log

2015-07-29 new file: RFID_Network/.DS_Store new file: RFID_Network/Hardware/.DS_Store new file: RFID_Network/Hardware/Eagle/Arduino_Shield.b#1 new file: RFID_Network/Hardware/Eagle/Arduino_Shield.b#2 new file: 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
    [Arduino_Shield.brd, Arduino_Shield.sch, Data_Interlock.brd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]
2015-07-29 Deleted old eagle files
    [Arduino_Shield.brd, Arduino_Shield.sch, Data_Interlock.brd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]
2015-07-29 This stupid thing deleted everything. Trying to add them back.
    [Arduino_Shield.brd, Arduino_Shield.sch, Data_Interlock.brd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]
2015-08-03 Updated SignIn code to fix the multi read error and to function with the RFID.php and the new hex format for the ID.
    [SignIn_Station.pde]
2015-08-03 Aug 3: added LCD, LED displays, error handling and syntax fixes
    [SignIn_Station.pde]
2015-08-05 adding enclosure models repo, and signin enclosure design STL files
    [Signin Enclosure Bottom.skp, Signin Enclosure Bottom.stl, Signin Enclosure Middle.skp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]
2015-08-05 enclosure modification
    [Signin Enclosure Bottom.skp, Signin Enclosure Bottom.stl, Signin Enclosure Bottom~.skp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]
2015-08-05 enclosure files and software debug
2015-08-06 Moving things into the appropriate folders
    [Signin Enclosure Bottom.skp, Signin Enclosure Bottom.stl, Signin Enclosure Bottom~.skp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]
2015-08-06 Added assembly of signin station
    [SIgnInV1_Assy.skp]
2015-08-17 Adding altered libraries
    [Frame.STL, SIgnInV1_Assy.skp, Signin Enclosure Bottom.skp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]
2015-08-19 updating signin.pde and adding relays.pde
2015-09-07 final versions of signin and relay software, sept 7
2015-10-01 Scripts and 'no id in db' timer fix
2015-10-08 adding 30second access relay
2015-11-12 updating with pro-shield
    [Pro_Shield_V1.sch]
2016-01-11 Updating EAGLE files
    [Pro_Shield_V1.brd, USB_Interlock_V2.brd, USB_Interlock_V2.sch]
2016-01-22 New boards, terminal enclosures, and labview interface
    Former-commit-id: 246ca6c8f016e846ca299188d99d46875b994b37
    [Pro_Shield_V1.brd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]
2016-01-24 print array
2016-01-27 Updating relay.pde. Correcting GET discrepency with rfid.php
    Former-commit-id: b77238e92873a3ff46766ce028b5121678333ddf
    [Relays.pde]
2016-01-27 File Cleanup
    Former-commit-id: ab2dfde575aa20bc2a914815df67f4b92a4f16c1
    [USB_Interlock_V3.GBL, USB_Interlock_V3.GBO, USB_Interlock_V3.GBS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]
2016-02-01 Update to arduino stuff for LCD fix. More to come.
    Former-commit-id: 047aca626a60cc439cf33ff01ea01eedb341d17f
    [Relays.pde, Test_Send.ino]
2016-02-02 tidying relays.pde and adding lcd_init fxn
2016-03-22 Updating Eagle Files for compatibility
    [Arduino_Shield.brd, Arduino_Shield.sch, BD_LLC_USB_Interlock_Flipped.brd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]
2016-07-06 Added backup of relay due to weirdness to be figured out later
2016-07-06 adding wokring python relay files
2016-08-10 updating Raspberry Pi Source code in Source_Code/RFID_C

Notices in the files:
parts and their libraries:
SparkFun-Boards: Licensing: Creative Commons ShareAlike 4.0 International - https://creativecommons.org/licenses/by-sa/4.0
